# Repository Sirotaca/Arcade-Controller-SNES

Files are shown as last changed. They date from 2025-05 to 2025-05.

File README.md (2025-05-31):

# Arcade Controller PCB for SNES
PCB for DIY arcade-style controllers for SNES using all through-hole components for ease of hand soldering. An Arduino Nano can optionally be added for input monitoring on a PC using the RetroSpy software. Designed to accept a 20-pin wiring harness using the common Brook UFB pinout.

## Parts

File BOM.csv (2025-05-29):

Reference | Value | Datasheet | Footprint | Qty | DNP
A1 | Arduino_Nano_v3.x | http://www.mouser.com/pdfdocs/Gravitech_Arduino_Nano3_0.pdf | Module:Arduino_Nano | 1
C1,C2,C3,C4 | 0.1u | ~ | Resistor_THT:R_Axial_DIN0207_L6.3mm_D2.5mm_P7.62mm_Horizontal | 4
J1 | Conn_01x05 | ~ | Connector_PinHeader_2.54mm:PinHeader_1x05_P2.54mm_Vertical | 1
J2 | Conn_02x10_Odd_Even | ~ | Connector_PinHeader_2.54mm:PinHeader_2x10_P2.54mm_Vertical | 1
RN1,RN2 | 10k | http://www.vishay.com/docs/31509/csc.pdf | Resistor_THT:R_Array_SIP9 | 2
U1,U2 | CD4021BE | https://assets.nexperia.com/documents/data-sheet/HEF4021B.pdf | Package_DIP:DIP-16_W7.62mm | 2
U3,U4 | 74HCT00 | http://www.ti.com/lit/gpn/sn74hct00 | Package_DIP:DIP-14_W7.62mm | 2

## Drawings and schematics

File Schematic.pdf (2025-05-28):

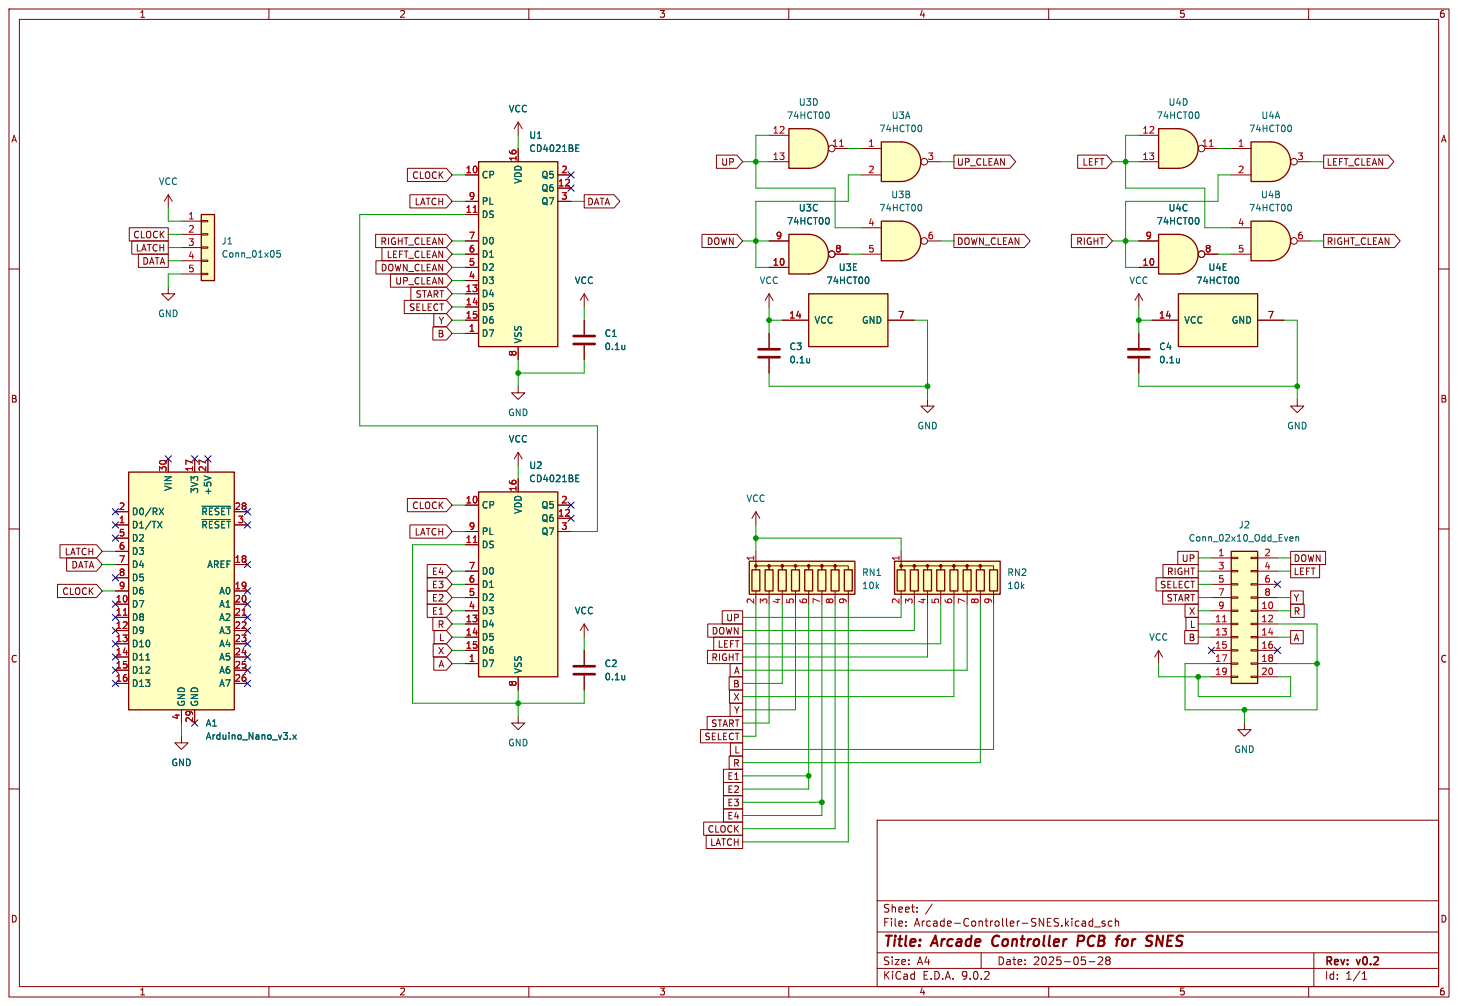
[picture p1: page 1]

File: Arcade-Controller-SNES.kicad_sch Sheet: / 1 2

Id: 1/1 Title: Arcade Controller PCB for SNES

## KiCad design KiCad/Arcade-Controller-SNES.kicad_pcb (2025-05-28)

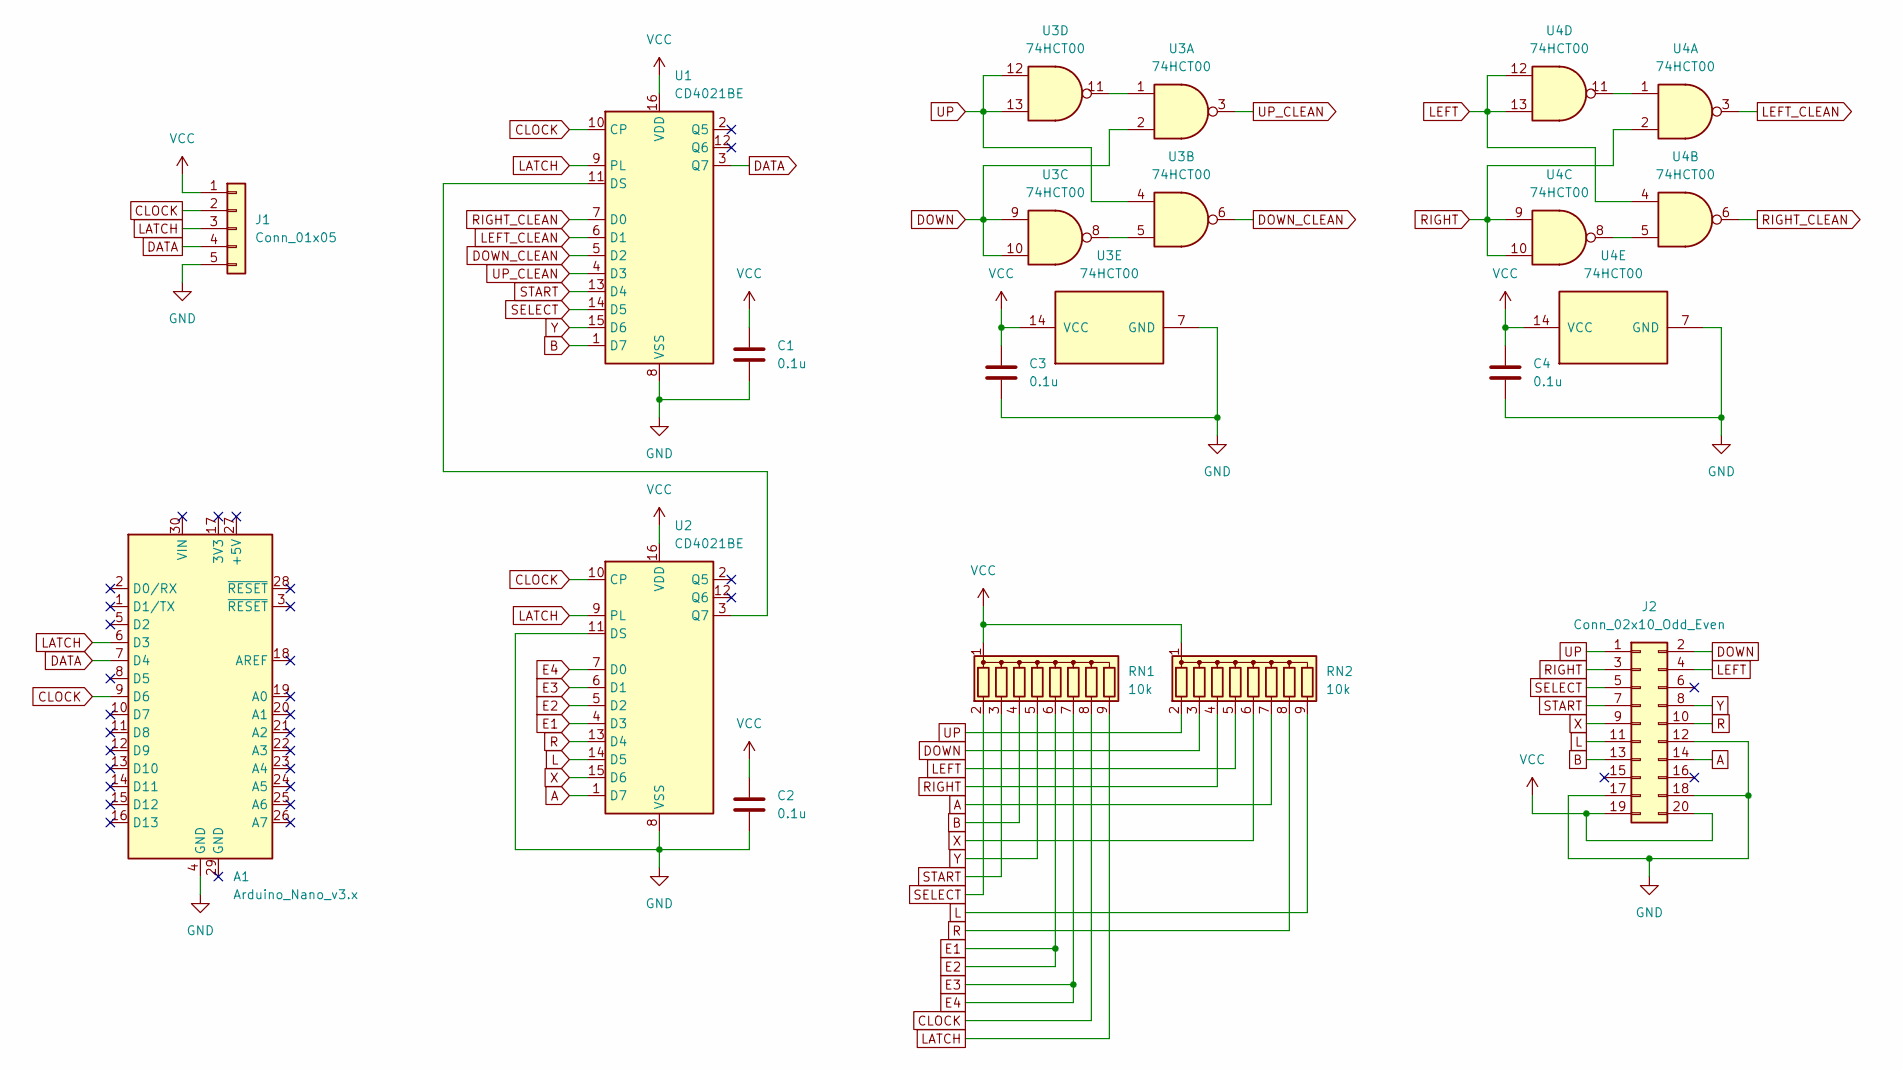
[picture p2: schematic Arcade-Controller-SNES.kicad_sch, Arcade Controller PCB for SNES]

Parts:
A1: Arduino_Nano_v3.x; Arduino_Nano
C1, C2, C3, C4: 0.1u; R_Axial_DIN0207_L6.3mm_D2.5mm_P7.62mm_Horizontal
J1: Conn_01x05; PinHeader_1x05_P2.54mm_Vertical
J2: Conn_02x10_Odd_Even; PinHeader_2x10_P2.54mm_Vertical
RN1, RN2: 10k; R_Array_SIP9
U1, U2: CD4021BE; DIP-16_W7.62mm
U3, U4: 74HCT00; DIP-14_W7.62mm

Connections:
A: J2.14, RN2.7 (R6), U2.1 (D7)
B: J2.13, RN1.4 (R3), U1.1 (D7)
CLOCK: A1.9 (D6), J1.2, RN1.8 (R7), U1.10 (CP), U2.10 (CP)
DATA: A1.7 (D4), J1.4, U1.3 (Q7)
DOWN: J2.2, RN2.3 (R2), U3.2, U3.9, U3.10
DOWN_CLEAN: U1.5 (D2), U3.6
E1: RN1.6 (R5), U2.4 (D3), U2.5 (D2)
E3: RN1.7 (R6), U2.6 (D1), U2.7 (D0)
GND: A1.4 (GND), C1.2, C2.2, C3.1, C4.1, J1.5, J2.12, J2.17, J2.18, U1.8 (VSS), U2.8 (VSS), U2.11 (DS), U3.7 (GND), U4.7 (GND)
L: J2.11, RN2.9 (R8), U2.14 (D5)
LATCH: A1.6 (D3), J1.3, RN1.9 (R8), U1.9 (PL), U2.9 (PL)
LEFT: J2.4, RN2.5 (R4), U4.4, U4.12, U4.13
LEFT_CLEAN: U1.6 (D1), U4.3
unnamed: U1.11 (DS), U2.3 (Q7)
unnamed: U3.1, U3.11
unnamed: U3.5, U3.8
unnamed: U4.1, U4.11
unnamed: U4.5, U4.8
R: J2.10, RN2.8 (R7), U2.13 (D4)
RIGHT: J2.3, RN2.4 (R3), U4.2, U4.9, U4.10
RIGHT_CLEAN: U1.7 (D0), U4.6
SELECT: J2.5, RN1.2 (R1), U1.14 (D5)
START: J2.7, RN1.3 (R2), U1.13 (D4)
UP: J2.1, RN2.2 (R1), U3.4, U3.12, U3.13
UP_CLEAN: U1.4 (D3), U3.3
VCC: C1.1, C2.1, C3.2, C4.2, J1.1, J2.19, J2.20, RN1.1 (common), RN2.1 (common), U1.16 (VDD), U2.16 (VDD), U3.14 (VCC), U4.14 (VCC)
X: J2.9, RN2.6 (R5), U2.15 (D6)
Y: J2.8, RN1.5 (R4), U1.15 (D6)

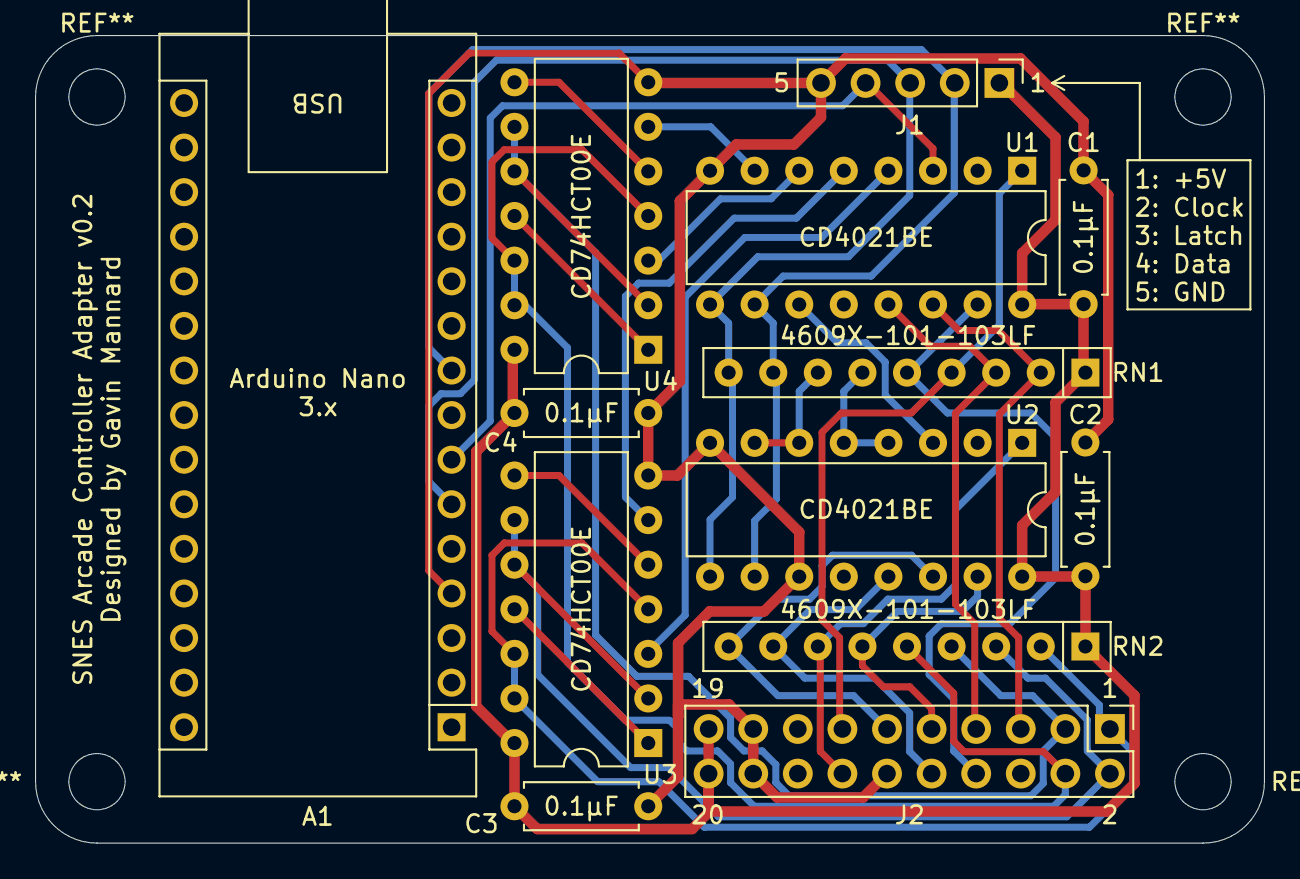
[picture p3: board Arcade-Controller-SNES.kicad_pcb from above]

Board: 2 copper layers, 70.0 x 46.0 mm, 13 parts (0 on the bottom side), 28 nets.
